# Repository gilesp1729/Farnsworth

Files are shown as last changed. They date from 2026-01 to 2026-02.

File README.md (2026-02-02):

# Farnsworth

"i can wire anything into anything!!" - Prof. Hubert J Farnsworth

### Control VESC motor by pedelec and display data via BLE

This version is for Bafang M510 and other mid motors that have an analog torque sensor and quadrature cadence sensors. 

### Scope

To allow gutted (motor only) Bafang mid motors to be controlled by an externally mounted VESC, and allow users to have full control. It addionally outputs speed, cadence and power data via the BLE Cycle Power service to popular cycling apps (such as SuperCycle), or full motor parameters to the [Babelfish app for VESC](https://github.com/gilesp1729/Babelfish).

### Sensors used

* 6-pin analog torque/cadence sensor in M510 or M560 motor (the CAN bus ones are not supported). Depending on the motor they have different counts of pulses per crank revolution.

* 2-pin temp sensor (there are no Hall sensors in these motors)

* Speed sensor (I used a Bosch one because it's much easier being only 2-wire, but any active-low sensor would do)

### Runs on

Arduino Nano 33 BLE or BLE Sense. Any VESC should work if it has the standard inputs for UART and motor temp.

### Library dependencies

* VESCUart

* ArduinoBLE

* RunningAverage

### Some pictures of the  build

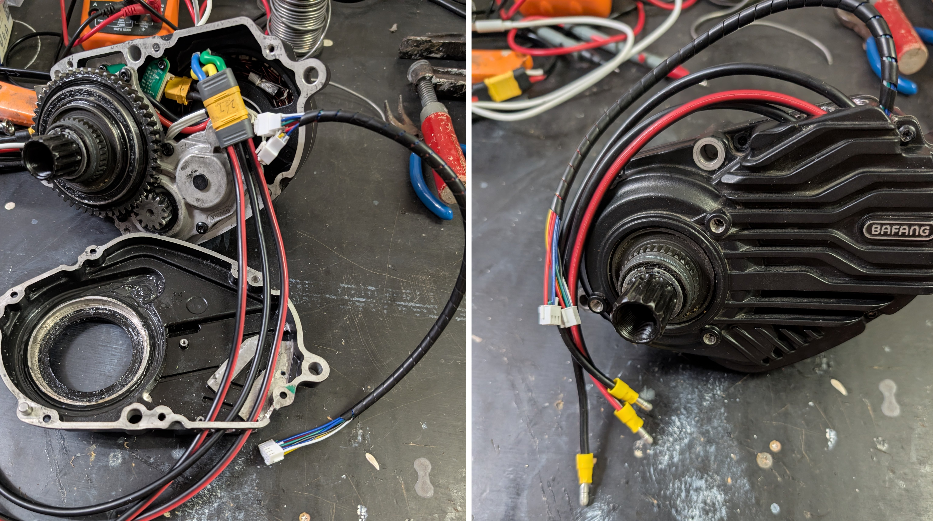
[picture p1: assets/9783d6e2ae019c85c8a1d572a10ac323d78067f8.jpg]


The phase wires and the torque sensor/temp sensor wires come out of the top of the motor housing.  The sensor wires use [PHB2.0mm 2x3P](https://www.aliexpress.com/item/1005009108741866.html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) plugs while the phases use an MR60 plug inside the motor and 4mm bullet pins to interface with the VESC.

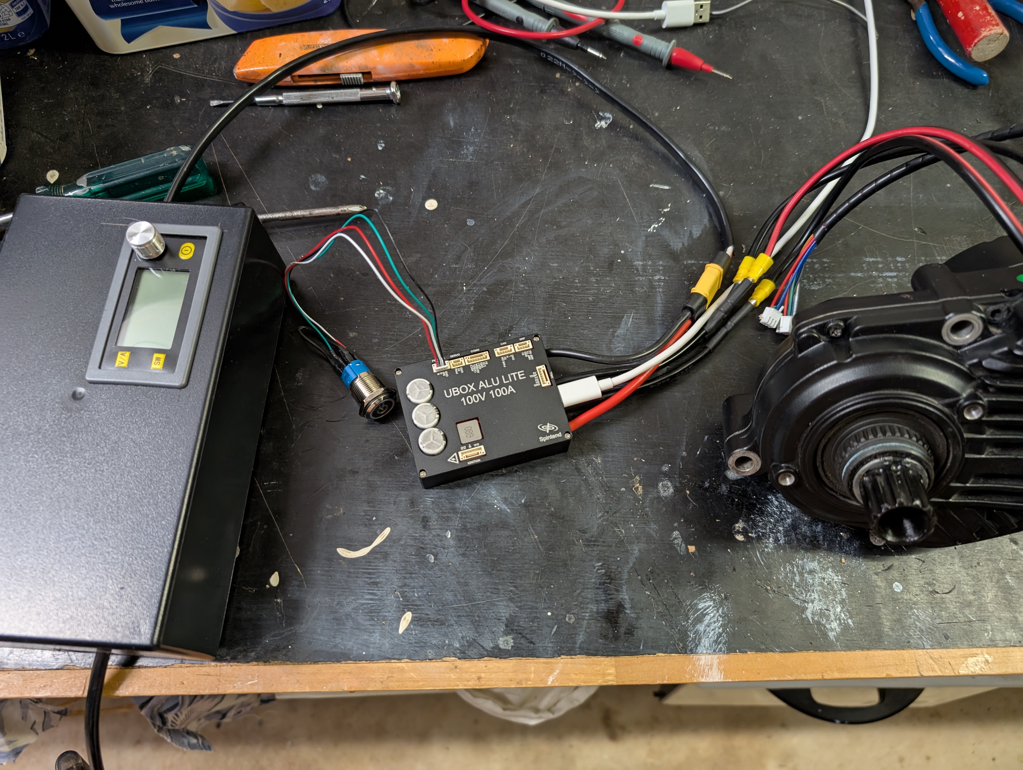
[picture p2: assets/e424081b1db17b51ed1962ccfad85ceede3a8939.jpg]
2025-12-16 16.35.41.jpg


Testing the motor with the [Spintend Ubox 100V/100A Vesc](https://spintend.com/collections/esc-based-on-vesc/products/single-ubox-aluminum-controller-100v-100a-based-on-vesc). On the left is a cheap [20 amp buck converter](https://www.kogan.com/au/buy/connecttriad-cnc-adjustable-power-supply-20a-1200w-lcd-display-is34049-1-ctxxy-0515/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) that takes 48V in from the battery and allows current limiting and reduced voltage for testing.

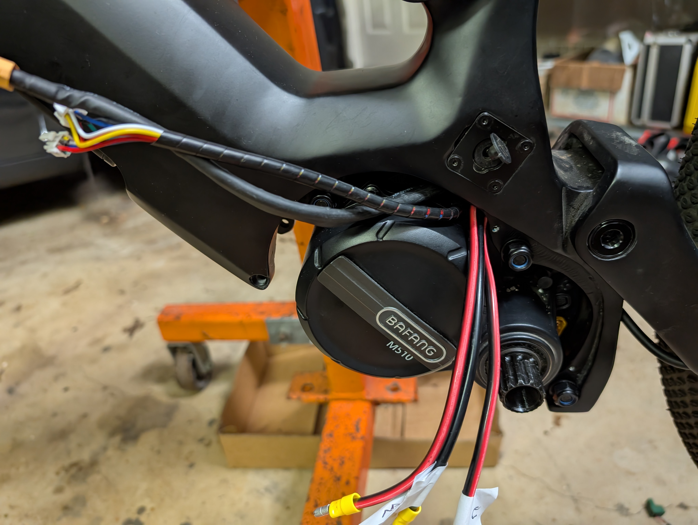
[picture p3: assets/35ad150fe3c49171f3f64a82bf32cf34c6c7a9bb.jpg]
2026-01-03 14.32.52.jpg


The wires are led out on the left side, since it's the only place the gap is large enough without cutting the carbon fibre (which I was not going to do)

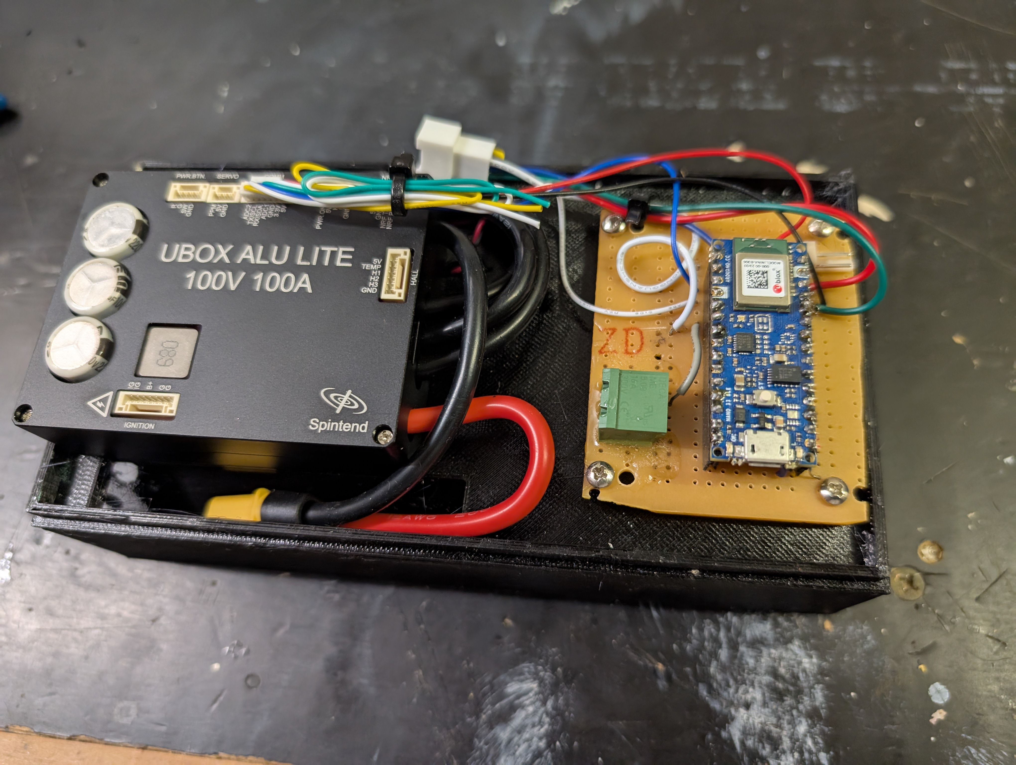
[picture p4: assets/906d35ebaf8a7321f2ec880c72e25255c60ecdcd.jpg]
2026-01-03 14.46.38.jpg


The VESC and Arduino Nano 33BLE mounted on the 3D-printed cradle. This is shaped to fit the frame just below the shock and has a gap below for a small heatsink (from an old graphics card) stuck on the VESC. The VESC runs cool. 

* 0.1uF caps for noise suppression on speed and cadence lines are not on board yet.

* The green connector is for the speed sensor (open collector two-wire Hall from Bosch)

* The torque sensor uses only 4 of the 6 wires: +5V, GND, SD and analog torque. SD is 3.3V logic, while the torque is divided down to keep voltages exceeding 3.3 out of the Arduino.

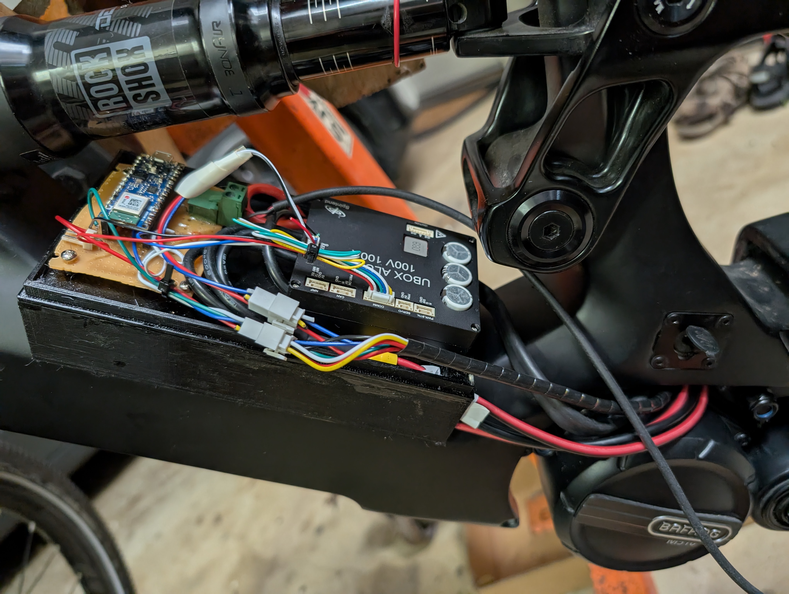
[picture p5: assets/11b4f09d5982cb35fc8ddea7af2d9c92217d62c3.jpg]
2026-01-03 15.00.54.jpg


Like this.

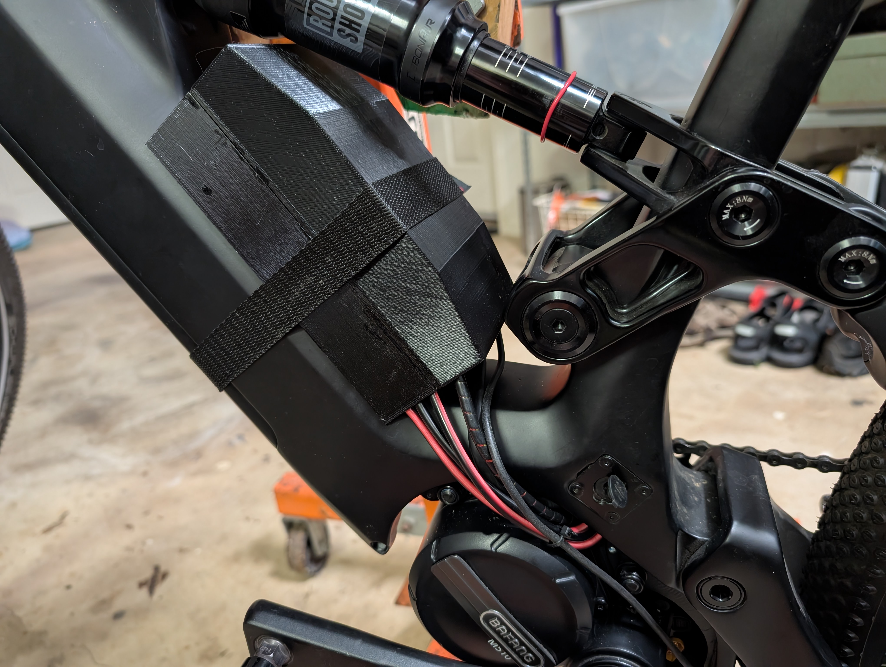
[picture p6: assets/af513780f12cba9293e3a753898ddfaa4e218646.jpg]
2026-01-07 15.51.30.jpg


The lid is made in two halves so it can be slipped in under the shock. It's not waterproof but I won't be fording any creeks with it.

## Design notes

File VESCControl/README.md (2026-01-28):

# VESCControl

"i can wire anything into anything!!" - Prof. Hubert J Farnsworth

VESCControl is a simple sketch for running a motor on the VESC and testing the connectons from the Arduino.

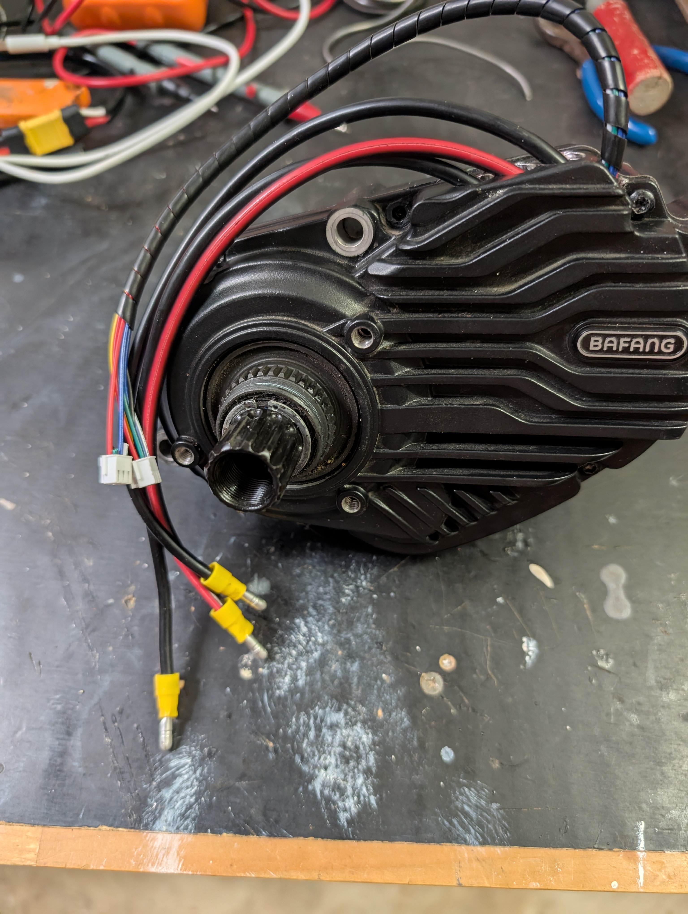
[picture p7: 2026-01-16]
assets/3ccfc992c697a2d6f8c4b93b70c74b9ae4ecf7f2.jpg

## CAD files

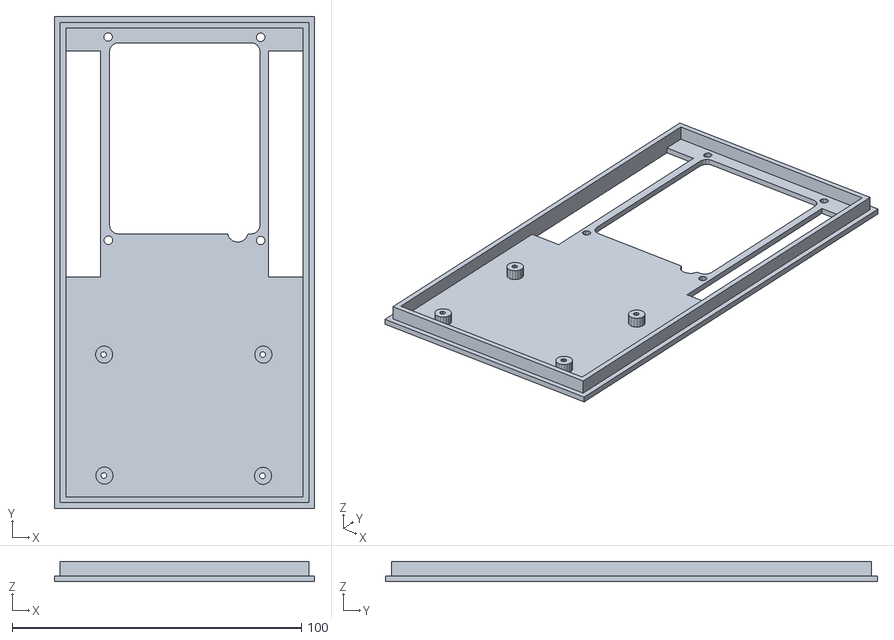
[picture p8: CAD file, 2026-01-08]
3D Prints/Floor.STL
90.0 x 170.0 x 7.00

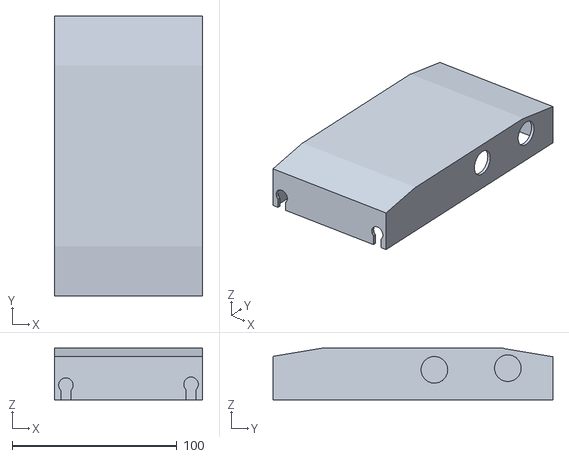
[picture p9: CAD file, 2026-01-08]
3D Prints/Lid.STL
90.0 x 170.0 x 31.5

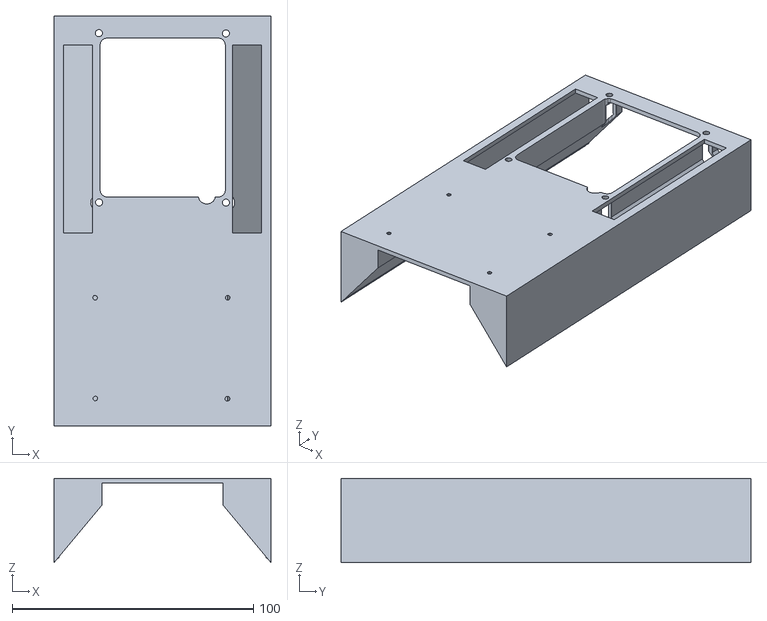
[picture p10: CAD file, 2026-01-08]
3D Prints/Cradle.STL
90.0 x 170.0 x 35.0

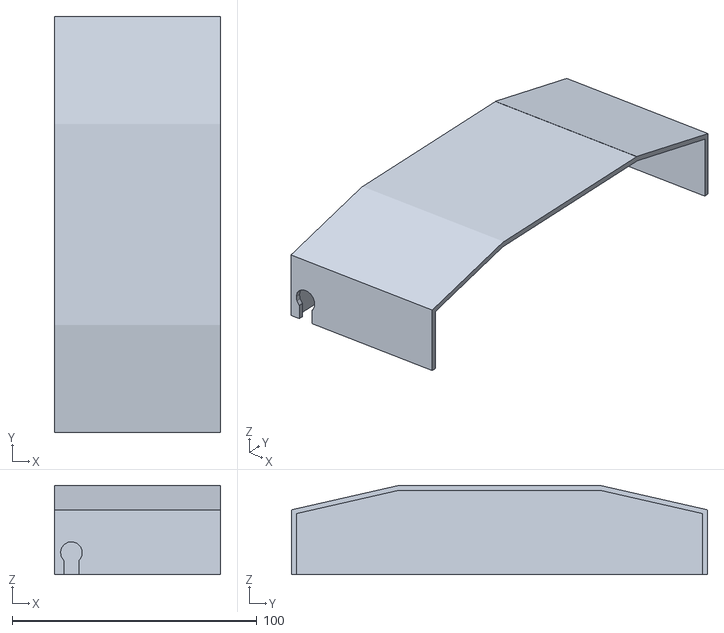
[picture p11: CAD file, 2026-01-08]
3D Prints/Lid-LH.STL
68.0 x 170.0 x 36.5

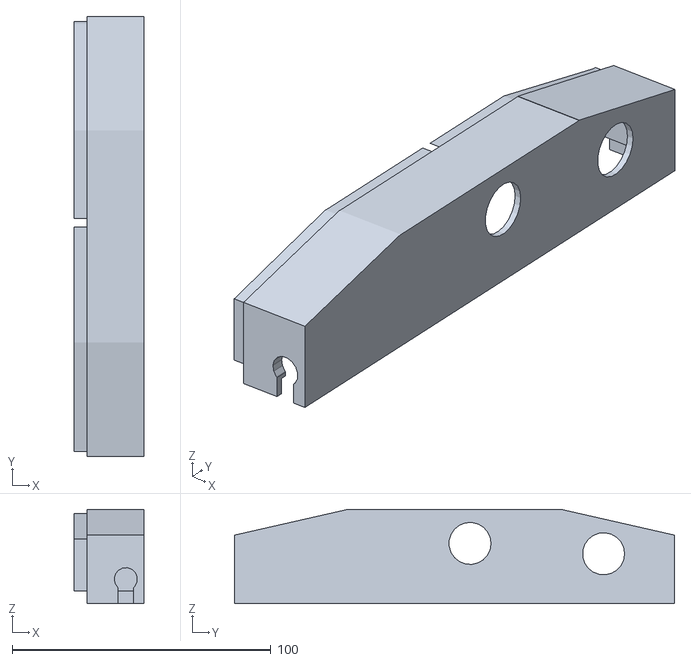
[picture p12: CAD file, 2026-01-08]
3D Prints/Lid-RH.STL
27.0 x 170.0 x 36.5

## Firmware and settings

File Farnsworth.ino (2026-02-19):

#include <ArduinoBLE.h>
#include <RunningAverage.h>
#include <NanoBLEFlashPrefs.h>
#include <VescUart.h>

// Farnsworth

// Open source cycle display and pedelec speed controller.
// Controls VESC and reports via BLE using CP and Babelfish protocol.

#include "constants.h"
#include "poller.h"

/** Initiate VescUart class */
VescUart VU;

// Service and characteristics
BLEService CyclePowerService("1818");
BLECharacteristic CyclePowerFeature("2A65", BLERead, 4);
BLECharacteristic CyclePowerMeasurement("2A63", BLERead | BLENotify, 14);
BLECharacteristic CyclePowerSensorLocation("2A5D", BLERead, 1);

// Battery service, in case it is needed. Even if not, it keeps
// the display tidy on apps that display it
BLEService batteryService("180F");

// Battery Level Characteristic
BLEUnsignedCharCharacteristic batteryLevelChar("2A19", BLERead | BLENotify);
int BatteryPercent = 100;  // start with 100% full

// Babelfish motor service and characteristics
BLEService motorService("FFF0");
BLECharacteristic motorMeasurement("FFF1", BLERead | BLENotify, 21);
BLECharacteristic motorSettings("FFF2", BLERead | BLENotify, 7);
BLECharacteristic motorNewSettings("FFF3", BLEWrite, 7);

int sensor_pos = 11;      // sensor position magic number.
// No idea what they mean (shitty specs) but it's mandatory to supply one.

unsigned char bleBuffer[17];
unsigned char slBuffer[1];
unsigned char fBuffer[4];
int connected = 0;
int vesc_connected = 0;

// Feature bits: bit 2 - wheel pair present, bit 3 - crank pair present
unsigned short feature_bits = 0x0C;

// Flags bits: bit 4 - wheel pair present, bit 5 - crank pair present
unsigned short flags = 0x30;

// Torque sensor reading with no force on pedal
float static_torque;

// Moving average filter for torque readings
RunningAverage torqueFilter(FILTER_SIZE);

// Access to the flash (non-volatile) memory
NanoBLEFlashPrefs flash;

// Poller for the wheel and crank pins
Poller Wheel(WHEEL_PIN);
Poller Crank(CRANK_PIN);

// Access to the flash (non-volatile) memory
//NanoBLEFlashPrefs flash;


// Timing and counters
volatile unsigned long previousMillis = 0;
volatile unsigned long previousPowerCalc = 0;
volatile unsigned long currentMillis = 0;

// Debouncing counters for wheel and crank interrupt routines
volatile unsigned long time_prev_wheel = 0, time_now_wheel;
volatile unsigned long time_prev_crank = 0, time_now_crank;
volatile unsigned long time_chat_wheel = 50;  // dead zone for bounces
volatile unsigned long time_chat_crank = 10;  // dead zone for bounces (crank)

// Counters for updating power and speed services
volatile unsigned long wheelRev = 0;
volatile unsigned long oldWheelRev = 0;
volatile unsigned long oldWheelMillis = 0;  // last time sent to BLE
volatile unsigned long lastWheeltime = 0;   // last time measurement taken
// Note: the wheel time is in half-ms (1/2048 sec), unlike CSC where it is in ms
volatile float raw_torque = 0;              // torque in Nm read from sensor
volatile float torque = 0;                  // averaged torque in Nm
volatile float speed = 0;                   // calculated speed in km/h
volatile float crpm = 0;                    // calculated crank rpm
short power = 0;                            // motor power in watts
float req_amps;                             // requested amps sent to VESC

// Wheel circumference and initial speed limit for motor
unsigned long circ = 2300;            // mm
unsigned long speed_limit = 2500;     // km/h*100

// Odometer rev counter in mm*100 (so steps of 23 for a 2300mm circ)
unsigned long odometer = 0;

// Ramp down speed from speed_limit to speed_lnmit + speed_ramp
float speed_ramp = 4.0;

// PAS level for motor (1 = eco, 2 = tour, 3 = sport, etc. up to 5)
int pas = 3;

// PAS level multipliers for 5 PAS levels. 
float pas_mult[6] = { 0, 1.0, 1.8, 2.4, 3.6, 4.5};

// Counters for cadence reporting
volatile unsigned long time_prev_crank_avg = 0;
volatile unsigned int crankPulsesRev = 0;   // pulse counter for whole revolutions
volatile unsigned int crankPulsesCad = 0;   // pulse counter for averaging out cadence measurement
volatile unsigned int crankRev = 0;         // rev counter for CSC/CP reporting
volatile unsigned int oldCrankRev = 0;
volatile unsigned long lastCranktime = 0;   // time counter for CSC/CP reporting
volatile unsigned long oldCrankMillis = 0;


// Fill the CP measurement array and send it
void fillCP()
{
  // Fill the CP measurement characteristic.
  int n = 0;  // to facilitate adding and removing stuff
  bleBuffer[n++] = flags & 0xff;
  bleBuffer[n++] = (flags >> 8) & 0xff;
  bleBuffer[n++] = power & 0xff;
  bleBuffer[n++] = (power >> 8) & 0xff;
  bleBuffer[n++] = wheelRev & 0xff;
  bleBuffer[n++] = (wheelRev >> 8) & 0xff;  // UInt32
  bleBuffer[n++] = (wheelRev >> 16) & 0xff;
  bleBuffer[n++] = (wheelRev >> 24) & 0xff;
  bleBuffer[n++] = lastWheeltime & 0xff;
  bleBuffer[n++] = (lastWheeltime >> 8) & 0xff;
  bleBuffer[n++] = crankRev & 0xff;
  bleBuffer[n++] = (crankRev >> 8) & 0xff;
  bleBuffer[n++] = lastCranktime & 0xff;
  bleBuffer[n++] = (lastCranktime >> 8) & 0xff;

  CyclePowerMeasurement.writeValue(bleBuffer, n);

  // Fill the battery % and some motor characteristics.
  if (vesc_connected)
  {
    // Assume 100% SOC is 4V per cell, 0% is 3V.
    BatteryPercent = 100 * ((VU.data.inpVoltage / NUM_SERIES_CELLS) - 3);
    if (BatteryPercent < 0)
      BatteryPercent = 0;
    else if (BatteryPercent > 100)
      BatteryPercent = 100;
    batteryLevelChar.writeValue(BatteryPercent);
  }
}

// Fill the motor service characteristics and send them
void fillMS()
{
  // Some integer values needed for the Babelfish protocol
  uint16_t volts100 = VU.data.inpVoltage * 100;
  uint16_t amps100 = VU.data.avgInputCurrent * 100;
  uint16_t req_amps100 = req_amps * 100;
  uint16_t kmh100 = speed * 100;
  uint16_t phase_amps100 = VU.data.avgMotorCurrent * 100;
  uint8_t duty_percent = VU.data.dutyCycleNow * 100;

  int n = 0;  // to facilitate adding and removing stuff
  bleBuffer[n++] = kmh100 & 0xff;		                // speed in km/h*100
  bleBuffer[n++] = (kmh100 >> 8) & 0xff;	   
  bleBuffer[n++] = crpm;			                      // cadence in rpm
  bleBuffer[n++] = power & 0xff;		                // motor power in watts
  bleBuffer[n++] = (power >> 8) & 0xff;	   
  bleBuffer[n++] = volts100 & 0xff;		              // battery volts*100
  bleBuffer[n++] = (volts100 >> 8) & 0xff;	   
  bleBuffer[n++] = amps100 & 0xff;		              // motor input current in amps*100
  bleBuffer[n++] = (amps100 >> 8) & 0xff;	   
  bleBuffer[n++] = req_amps100 & 0xff;		          // requested motor current in amps*100
  bleBuffer[n++] = (req_amps100 >> 8) & 0xff;				      
  bleBuffer[n++] = pas;			                          // Unused (PAS left here for backward compatibility)
  bleBuffer[n++] = (uint8_t)(VU.data.tempMotor + 40);		// Motor temp in degC + 40			      
  bleBuffer[n++] = (uint8_t)(VU.data.tempMosfet + 40);	// Controller temp in degC + 40		      
  bleBuffer[n++] = duty_percent;                      // Duty cycle in percent
  bleBuffer[n++] = phase_amps100 & 0xff;		          // motor phase current in amps*100
  bleBuffer[n++] = (phase_amps100 >> 8) & 0xff;	  
  bleBuffer[n++] = odometer & 0xff;
  bleBuffer[n++] = (odometer >> 8) & 0xff;  // UInt32
  bleBuffer[n++] = (odometer >> 16) & 0xff;
  bleBuffer[n++] = (odometer >> 24) & 0xff;

  motorMeasurement.writeValue(bleBuffer, n);				      

  n = 0;								      
  bleBuffer[n++] = speed_limit & 0xff;		        // speed limit in km/h*100		      
  bleBuffer[n++] = (speed_limit >> 8) & 0xff;
  bleBuffer[n++] = circ & 0xff;		                  // wheel circumference in mm
  bleBuffer[n++] = (circ >> 8) & 0xff;
  bleBuffer[n++] = pas;                             // PAS level (0-5)
  bleBuffer[n++] = 0;
  bleBuffer[n++] = 0;
  motorSettings.writeValue(bleBuffer, n);
}

// Check if writable characteristics have changed from the central.
void check_writable_chars()
{
  unsigned long new_circ;

  motorNewSettings.readValue(bleBuffer, 7);
  speed_limit = bleBuffer[0] + ((uint16_t)bleBuffer[1] << 8);
  new_circ = bleBuffer[2] + ((uint16_t)bleBuffer[3] << 8);
  pas = bleBuffer[4];

  // If circ has changed, save it to the flash.
  if (new_circ != circ)
  {
    circ = new_circ;
    updateFlash(false);
  }
}

// Get VESC stats
// This is very slow (100ms!) esp when no VESC is connected, so don't do it 
// very often.
void queryVESC()
{
  if ( VU.getVescValues() ) 
  {
    vesc_connected = true;

    // calculate the motor's actual input power
    power = VU.data.inpVoltage * VU.data.avgInputCurrent;
#if 0
    Serial.print("RPM ");
    Serial.print(VU.data.rpm / NUM_POLE_PAIRS);
    Serial.print(" Volts ");
    Serial.print(VU.data.inpVoltage);
    Serial.print(" Amps ");
    Serial.print(VU.data.avgInputCurrent);
    Serial.print(" Duty ");
    Serial.print(VU.data.dutyCycleNow);
    Serial.print(" Ctrl temp ");
    Serial.print(VU.data.tempMosfet);
    Serial.print(" Motor temp ");
    Serial.print(VU.data.tempMotor);
    Serial.println();
#endif
  }
  else
  {
    vesc_connected = false;
  }
}

// Update old values and send CP and CSC to BLE client
void update_chars(bool calc_power, String sType)
{
  queryVESC();

  // Update old values and send CP
  oldWheelRev = wheelRev;
  oldCrankRev = crankRev;
  oldWheelMillis = currentMillis;
  oldCrankMillis = currentMillis;
  previousMillis = currentMillis;
  fillCP();
  fillMS();

  // Some debug output to indicate what triggered the update
  Serial.print("Wheel Rev.: ");
  Serial.print(wheelRev);
  Serial.print(" WheelTime : ");
  Serial.print(lastWheeltime);
  Serial.print(" Crank Rev.: ");
  Serial.print(crankRev);
  Serial.print(" CrankTime : ");
  Serial.print(lastCranktime);
  Serial.print(" Speed : ");
  Serial.print(speed);
  Serial.print(" Cadence : ");
  Serial.print(crpm);
  Serial.print("  ");
  Serial.println(sType);

  Serial.print("Torque raw ");
  Serial.print(raw_torque);
  Serial.print("Torque avg ");
  Serial.print(torque);
  Serial.print(" Power : ");
  Serial.print(power);
  Serial.print(" Odo ");
  Serial.println(odometer);
}

// Interrupt routines trigger when a pulse is received (falling edge on pin)
void wheelAdd()
{
  time_now_wheel = millis();
  if (time_now_wheel > time_prev_wheel + time_chat_wheel)
  {
    // Calculate the speed in km/h based on wheel circumference
    speed = (circ * 3.6) / (time_now_wheel - time_prev_wheel);

    // Update the wheel counter and remember the time of last update
    wheelRev = wheelRev + 1;
    odometer = odometer + (circ / 100);
    time_prev_wheel = time_now_wheel;
    lastWheeltime = millis() << 1;
  }
}

// Take a torque sensor reading and convert it to an instananeous torque in Nm 
float readTorque()
{
  float read_torque = analogRead(TORQUE_PIN);   

  read_torque = (read_torque - static_torque) / TORQUE_SLOPE;
  if (read_torque < 0)
    read_torque = 0;
  return read_torque;
}

// Cadence sensor triggers 32 times per crank revolution. Maintain a separate counter.
void crankAdd()
{
  time_now_crank = millis();
  if (time_now_crank > time_prev_crank + time_chat_crank) 
  {
    // Read the torque every cadence pulse and add it in to the running average buffer.
    raw_torque = readTorque();
    torqueFilter.addValue(raw_torque);

    // Calculate the cadence rpm
    // The short inter-pulse intervals may need to be added over
    // a longer time, comparable to the torque filter
    if (++crankPulsesCad > PULSES_AVG_CAD)
    {
      crankPulsesCad = 0;
      crpm = 60000.0 / (AVG_PER_REV * (time_now_crank - time_prev_crank_avg));
      time_prev_crank_avg = time_now_crank;
    }

    // If we have completed a full revolution
    if (++crankPulsesRev > PULSES_PER_REV)
    {
      crankPulsesRev = 0;
      crankRev = crankRev + 1;
      lastCranktime = millis();
    }

    time_prev_crank = time_now_crank;
  }
}


// Calculate human power from peak torque and cadence. Multiply by the PAS multiplier
// and send it down to the VESC as a motor current setting.
void updateVESC()
{
  float watts;

  torque = torqueFilter.getMaxInBuffer();
  watts = torque * crpm * (TWO_PI / 60);   // the human average power in watts
  if (vesc_connected)
  {
    // Set motor current based on power and PAS multiplier.
    
    // Sanity check the current to be between 0 and MAX_AMPS.
    req_amps = pas_mult[pas] * watts / VU.data.inpVoltage;
    if (req_amps < 0)
      req_amps = 0;
    else if (req_amps > MAX_AMPS)
      req_amps = MAX_AMPS;

    // If speed limit has been exceeded, ramp down the current
    // and finally cut it off altogether.
    float lim = speed_limit / 100.0;
    if (speed > lim + speed_ramp)
      req_amps = 0;
    else if (speed > lim)
      req_amps *= 1.0 - ((speed - lim) / speed_ramp);

    VU.setCurrent(req_amps);
  }
}

// Update the odometer and circ in flash memory. Do this occasionally, when bike stops,
// when disconnecting, or when a new circ is sent from the central.
typedef struct FlashPrefs
{
  unsigned long odometer;
  unsigned long circ;
} FlashPrefs;

void updateFlash(bool clear)
{
  FlashPrefs prefs;
  
  if (clear)
  {
    flash.deletePrefs();
    flash.garbageCollection();
  }

  prefs.odometer = odometer;
  prefs.circ = circ;
  flash.writePrefs(&prefs, sizeof(prefs));  
}

// Read the flash contents at setup
void readFlash()
{
  FlashPrefs prefs;

  flash.readPrefs(&prefs, sizeof(prefs));
  odometer = prefs.odometer;
  circ = prefs.circ;
}

// if the wheel timer has not been updated for ~2 seconds, zero out the
// internal speed and cadence values, so the power resets to zero.
void zero_on_inactivity()
{
  if (currentMillis > time_prev_wheel + WHEEL_INACTIVITY_INTERVAL)
  {
    speed = 0;
    power = 0;

    // Write cumulative wheelRev to odometer in non-volatile here
    updateFlash(false);
  }

  // Similarly for the crank. Zero the filter out to provide a starting ramp
  // when next started up.
  if (currentMillis > time_prev_crank + CRANK_INACTIVITY_INTERVAL)
  {
    crpm = 0;
    power = 0;
    torqueFilter.fillValue(0, FILTER_SIZE);  
  }
}

void setup()
{
  int count = 0;
  char buf[20];
  char devname[32];

  Serial.begin(9600);  // initialize serial communication
  Serial1.begin(115200); // Initialise serial comms with VESC

  while (!Serial)
  {
    // Be sure to break out so we don't wait forever if no serial is connected
    if (count++ > 20)
      break;
    delay(100);
  }

  // Setup VESC UART on Serial1
  VU.setSerialPort(&Serial1);

  // Initialize the LED on pin 13 to indicate when a central is connected
  pinMode(LED_BUILTIN, OUTPUT);
  digitalWrite(LED_BUILTIN, LOW);

  // Initialise BLE and establish cycling power characteristics
  BLE.begin();
  strcpy(buf, BLE.address().c_str());
  Serial.print("My MAC address: ");
  Serial.println(buf);
  strcpy(devname, "Farnsworth");
  strcat(devname, buf + 12);
  BLE.setLocalName(devname);
  BLE.setAdvertisedService(CyclePowerService);
  CyclePowerService.addCharacteristic(CyclePowerFeature);
  CyclePowerService.addCharacteristic(CyclePowerMeasurement);
  CyclePowerService.addCharacteristic(CyclePowerSensorLocation);
  BLE.addService(CyclePowerService);

  // Establish Babelfish motor measurement service and its characteristics
  motorService.addCharacteristic(motorMeasurement);
  motorService.addCharacteristic(motorSettings);
  motorService.addCharacteristic(motorNewSettings);
  BLE.addService(motorService);

  // Don't advertise the battery service; it will be found when the app connects,
  // if the app is looking for it
  batteryService.addCharacteristic(batteryLevelChar);
  BLE.addService(batteryService);
  batteryLevelChar.writeValue(BatteryPercent);

  unsigned long t = millis();
  lastWheeltime = t << 1;       // this is in half-ms
  lastCranktime = t;
  torqueFilter.fillValue(0, FILTER_SIZE);   // fill torque running average buffer with zeroes
  Wheel.clear();
  Crank.clear();              // initialise running sum buffers

  // Read back odometer and circ from flash. Note that the speed limit is
  // not stored here as we want it to rever to 25km/h every startup
//#define CLEAR_FLASH
#ifdef CLEAR_FLASH  // define this once to clear it from the outset
  updateFlash(true);
#else
  readFlash();
#endif

  // Write the initial values of the CP (power) characteristics
  slBuffer[0] = sensor_pos & 0xff;
  fBuffer[0] = feature_bits & 0xff;   // little endian
  fBuffer[1] = 0x00;
  fBuffer[2] = 0x00;
  fBuffer[3] = 0x00;
  CyclePowerFeature.writeValue(fBuffer, 4);
  CyclePowerSensorLocation.writeValue(slBuffer, 1);
  fillCP();
  fillMS();

  // Attach the wheel and crank interrupt routines to their input pins
  // DONT DO THIS as the interrupts are really dodgy on the Nano 33BLE.
  // We will poll them instead.
  //attachInterrupt(digitalPinToInterrupt(WHEEL_PIN), wheelAdd, FALLING);
  //attachInterrupt(digitalPinToInterrupt(CRANK_PIN), crankAdd, FALLING);

  // Read the torque sensor ADC with no force on pedal.
  static_torque = analogRead(TORQUE_PIN);   
  Serial.print("Initial static torque ADC: ");
  Serial.println(static_torque);

  // Advertise that we are ready to go
  BLE.advertise();
  Serial.println("Bluetooth device active, waiting for connections...");
}

void loop()
{
  // listen for BLE peripherals to connect:
  BLEDevice central = BLE.central();

  // if a central is connected to peripheral:
  if (central)
  {
    Serial.print("Connected to central: ");
    // print the central's MAC address:
    Serial.println(central.address());
    // turn on the LED to indicate the connection:
    digitalWrite(LED_BUILTIN, HIGH);

    while (central.connected())
    {
      connected = 1;
      currentMillis = millis();
      Wheel.poll_pin(wheelAdd);
      Crank.poll_pin(crankAdd);

      // Check if connected central has updated the writable settings
      // (PAS, speed limit, wheel circ)
      check_writable_chars();

      // Check and report the wheel and crank measurements every REPORTING_INTERVAL ms
      if (oldWheelRev < wheelRev && currentMillis - oldWheelMillis >= REPORTING_INTERVAL)
      {
        update_chars(1, "wheel");
      }
      else if (oldCrankRev < crankRev && currentMillis - oldCrankMillis >= REPORTING_INTERVAL)
      {
        update_chars(1, "crank");
      }
      else if (currentMillis - previousMillis >= REPORTING_INTERVAL)
      {
        // simulate some speed on the wheel, 500ms per rev ~16km/h, 800ms ~10km/h
        //wheelAdd();
        //crankAdd();  // don't do this, it will look very slow (only 1/32 of a rev)
        // simulate some power output
        //power = 250;
        
        update_chars(0, "timer");
      }
      
      if (currentMillis - previousPowerCalc >= POWER_CALC_INTERVAL)
      {
        // Calculate human power from average torque and cadence. Multiply by the PAS level
        // and send it down to the VESC as motor power
        updateVESC();
        previousPowerCalc = currentMillis;
      }

      // Zero things if inactive
      zero_on_inactivity();
    }

    // when the central disconnects, turn off the LED, update the flash, and re-advertise.
    connected = 0;
    digitalWrite(LED_BUILTIN, LOW);
    updateFlash(false);
    Serial.print("Disconnected from central: ");
    Serial.println(central.address());
    BLE.advertise();
    Serial.println("Bluetooth device active, waiting for connections...");

    // Reinstate defaults in case we ride away without powering off and on
    speed_limit = 2500;
    pas = 3;
  }
  else
  {
    // No central is connected. We run with default parameters
    // (PAS level 3, 25km/h speed limit)
    currentMillis = millis();
    Wheel.poll_pin(wheelAdd);
    Crank.poll_pin(crankAdd);

    if (currentMillis - previousMillis >= REPORTING_INTERVAL)
    {
      //wheelAdd();
      update_chars(0, "timer");
    }

    if (currentMillis - previousPowerCalc >= POWER_CALC_INTERVAL)
    {
      // Calculate power from average torque and cadence. Multiply by the PAS multiplier
      // and send it down to the VESC
      updateVESC();
      previousPowerCalc = currentMillis;
    }

    // Zero things if inactive
    zero_on_inactivity();
  }
}

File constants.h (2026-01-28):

// Constants used by Farnsworth to interface to the VESC.

// Pins for wheel and cadence sensors
#define WHEEL_PIN 10

// SD pin from toque/cadence sensor (PAS1 and PAS2 are not used)
#define CRANK_PIN 2

// Torque sensor (analog) pin.
#define TORQUE_PIN A0

// Torque slope (ADC counts per Nm) Determined by experiment
// to reliably produce progressive torque values in Nm.
#define TORQUE_SLOPE  6.8

// Maxiumum amps sent to VESC. Should be <= the max current set in the VESC.
#define MAX_AMPS      12

// Cadence pulses per revolution of crank at the SD (speed/direction) line.
// The quadrature outputs (not used here) may be at this rate or half this rate.
// Some analog sensors gives 32 pulses/rev.
#define PULSES_PER_REV  46

// Cadence pulses per cadence averaging interval.
// Does not have to be a divisor of PULSES_PER_REV, but should be between 1/4 and 1/2.
// The number of averaging intervals per rev is precalculated here.
#define PULSES_AVG_CAD  12
#define AVG_PER_REV     ((float)PULSES_PER_REV / PULSES_AVG_CAD)

// Number of pole-pairs in the motor (only used for debugging prints)
#define NUM_POLE_PAIRS  5

// Number of nom. 3.7V Li cells in series in the battery pack
#define NUM_SERIES_CELLS  13

// Reporting interval in ms
#define REPORTING_INTERVAL    500

// Power calculation intrval in ms. 
#define POWER_CALC_INTERVAL   100

// Intervals (in ms) after which sensors are considered inactive
#define WHEEL_INACTIVITY_INTERVAL   2000
#define CRANK_INACTIVITY_INTERVAL   500

// Size of moving average filter for torque readings (they are read 
// once per cadence pulse, ~30-180 ms) They need to be collected
// over some part of a crank revolution, to smooth out dead spots and
// to provide a starting ramp. The maximum torque is taken for power
// calculations.
#define FILTER_SIZE 23

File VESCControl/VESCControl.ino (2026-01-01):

#include <VescUart.h>

/** Initiate VescUart class */
VescUart VU;

// Number of pole-pairs in the motor 
#define NUM_POLE_PAIRS  8

int duty = 0;
void setup() {

  /** Setup Serial port to display data */
  Serial.begin(9600);

  /** Setup UART port (Serial1). Baud rate matches VESC UART setup */
  Serial1.begin(115200);

  while (!Serial) {;}

  /** Define which ports to use as UART */
  VU.setSerialPort(&Serial1);
}

void loop()
{
  // Set VESC up for current, rpm or duty.
  if (Serial.available())
  {
    char buf[16];
    int len;
    char *p;

    // Accept and act on commands from the Serial monitor.
    // Anything that is not a command just gets echoed to the serial monitor.
    while (Serial.available())
    {
      len = Serial.readBytesUntil('\n', buf, 16);
      buf[len] = '\0';
      p = buf;
      Serial.println(buf);

      switch (*p++)
      {
        case 's':
        case 'S':
          // Stop the motor.
          VU.setCurrent(0);
          duty = 0;
          break;

        case 'd':
        case 'D':
          // Set duty cycle in percent.
          if (len <= 1)
            break;
          while (isspace(*p))
            p++;
          VU.setDuty(atoi(p) / 100.0f);
          break;

        case 'i':
        case 'I':
          // Set current in amps.
          if (len <= 1)
            break;
          while (isspace(*p))
            p++;
          VU.setCurrent(atoi(p));
          break;

        case 'r':
        case 'R':
          // Set speed in RPM.
          if (len <= 1)
            break;
          while (isspace(*p))
            p++;
          VU.setRPM(atoi(p) * NUM_POLE_PAIRS);
          break;
      }
    }
  }

  /** Call the function getVescValues() to acquire data from VESC */
  if ( VU.getVescValues() )
  {
    Serial.print("RPM ");
    Serial.print(VU.data.rpm / NUM_POLE_PAIRS);
    Serial.print(" Volts ");
    Serial.print(VU.data.inpVoltage);
    Serial.print(" Amps ");
    Serial.print(VU.data.avgInputCurrent);
    Serial.print(" Duty ");
    Serial.print(VU.data.dutyCycleNow);
    Serial.print(" Ctrl temp ");
    Serial.print(VU.data.tempMosfet);
    Serial.print(" Motor temp ");
    Serial.print(VU.data.tempMotor);
    Serial.println();
  }
  else
  {
    Serial.println("Failed to get data!");
  }

  delay(100);
}

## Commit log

2026-01-01 Initial commit. Compiles, that's all. Include VESCControl as a simple test program. The 3D prints are to come when I know they work.
2026-01-06 Some more implementation of Babelfish protocol. Boilerplate torque calculation (not calibrated yet)
2026-01-08 Calibrate toque sensor at startup. Replace running average with max in buffer to track peak torque. Some bug fixes.
    [Cradle.STL, Floor.STL, Lid-LH.STL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]
2026-01-12 Display requested amps as well as moto amps. Fix inaccurate integer division when calculating speed, and make in km/h from the beginning.
    [Farnsworth.ino, constants.h]
2026-01-16 Add some pictures and info to the readme. Misc bug fixes.
    [Farnsworth.ino]
2026-01-17 Implement PAS level writeback (move PAS to writable settings). Increase time_chat_crank to put a lid on silly cadence readings due to noise.
    [Farnsworth.ino]
2026-01-25 Only query VESC stats every reporting interval, not every power calculation (we only need the voltage, and it changes slowly)
2026-01-27 First commit of time-averaging polling to try and reduce noise effects on the cadence line. Untested.
    [Farnsworth.ino]
2026-01-28 Compute cadence over several crank pulses, as there is too much jitter if only using one. Update the 32 pulses/rev assumption to 46, after noticing that there were a lot more pulses per rev than I ha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
    [Farnsworth.ino, constants.h]
2026-01-28 Update the readme to reflect current standing.
2026-01-28 Add a readme for VESCControl.
2026-01-28 Reinstate default speed limit and pas when disconnecting central. Fix broken link in readme.
    [Farnsworth.ino, constants.h]
2026-02-02 Display motor power instead of requested motor power. Suffix device name with last 4 digits of MAC address to make it unique (in the manner of the old Babelfish). Implement power stripe inside speed 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
2026-02-19 Store odometer and wheel circ in flash memory. Add phase amps and duty to the display.
